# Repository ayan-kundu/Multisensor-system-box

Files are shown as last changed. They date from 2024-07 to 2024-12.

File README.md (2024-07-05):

# This is an Arduino IDE operational code 
## Hardware used: 
                  Arduino UNO with Adafruit SD card and RTC breakout module 
                  Sensors: 
                          Atlas CO2 industrial sesnor
                          RS 485 Soil probe sensor
                          RS 485 wall mountable Air sensor
                  Battery: 14.4V Li-ion rechargable battery 
## Running Software:
                  The software is customisable and optimised for the microcontroler and its computational capabilities alongside sesnor requirements for proper and robust communication 
                  In Code folder software sketch is included

### System in use: 
----It is a Prototype----
##### System Look
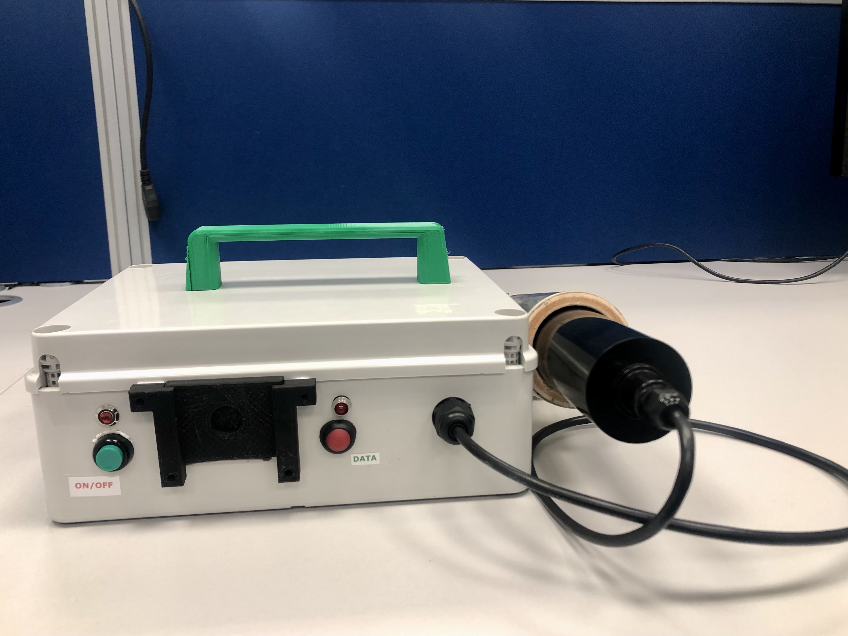
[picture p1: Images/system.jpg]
Multisesnor system box


##### In use On Desk
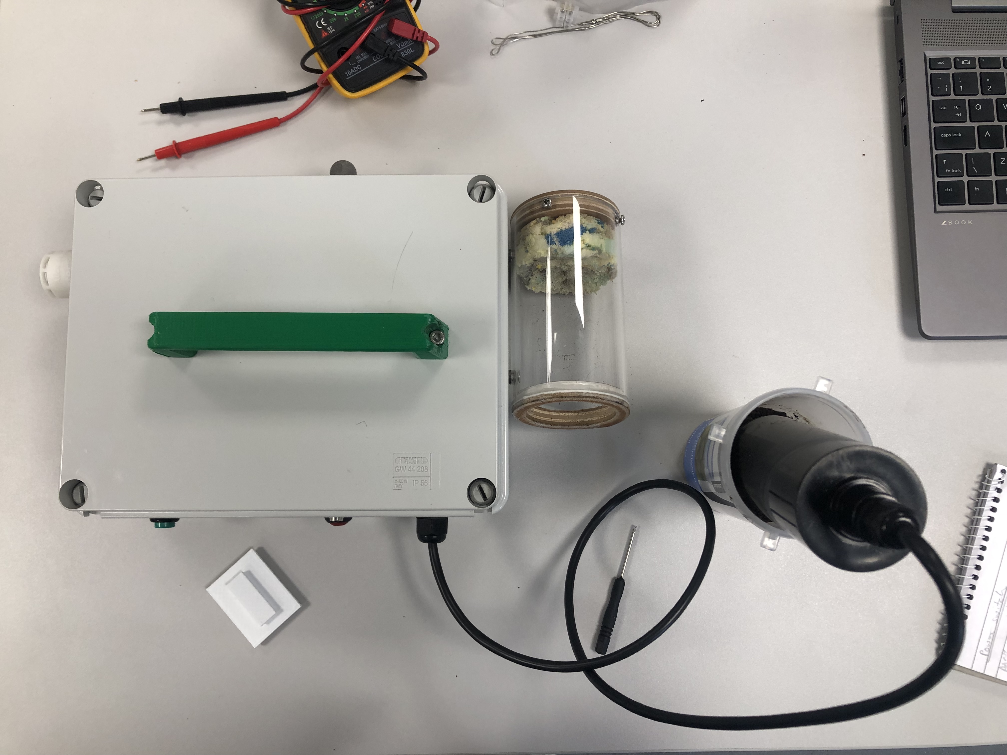
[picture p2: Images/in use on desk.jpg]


##### On Desk
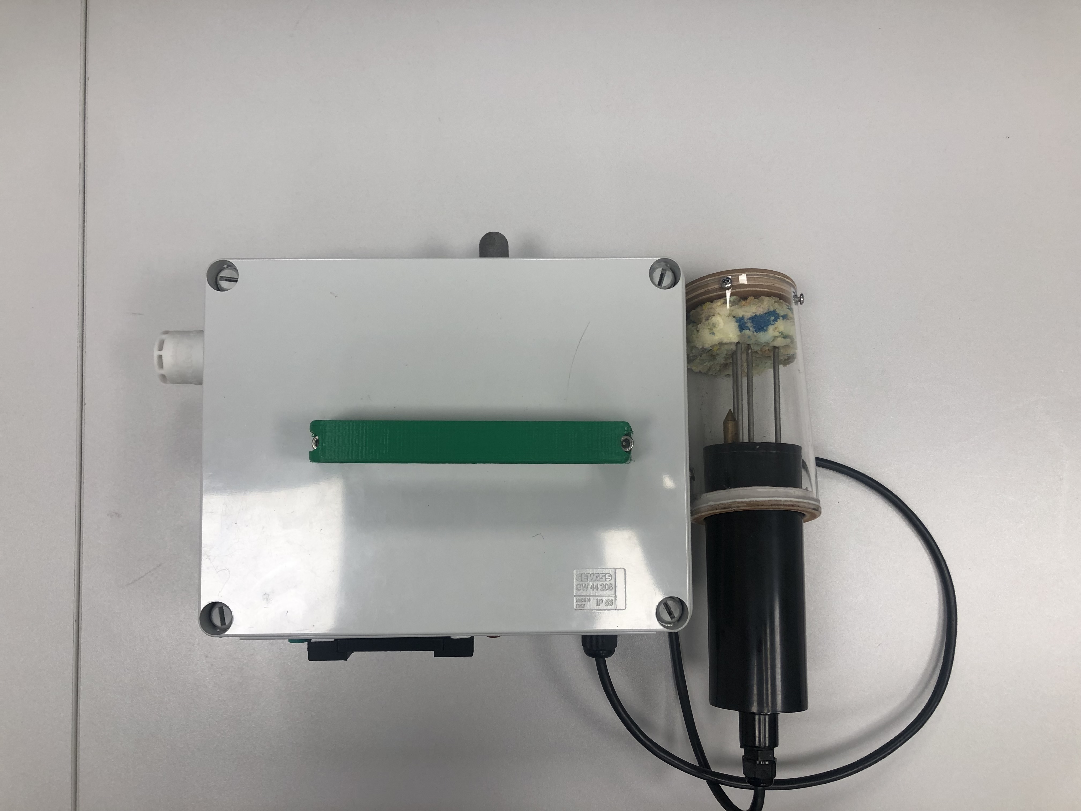
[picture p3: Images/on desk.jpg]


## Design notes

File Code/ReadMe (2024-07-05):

#Communication rrquirements for UNO
  Software serial alongside Altsoft Serial are used for communicating with RS485 and CO2 sensor respectedly
  CO2 sensor uses UART and AltsoftSerial is used for communication while Air and soil sensors use software serial for data interchange.
  Air and soil sensors use RS485 protocol and both of them are multidropped acrosse a Transiever names MAX485 which is connected to the arduino at one side whereas other side is attached to the sensor
  RX TX terminals 
#Optimisation was one of the most challenging part that came out as Arduino UNO has only 2K usable memories(Static and dynamic all together)
  Debugged version of the code is the latest and is more rubust to rough uses and stable reliable data encounter

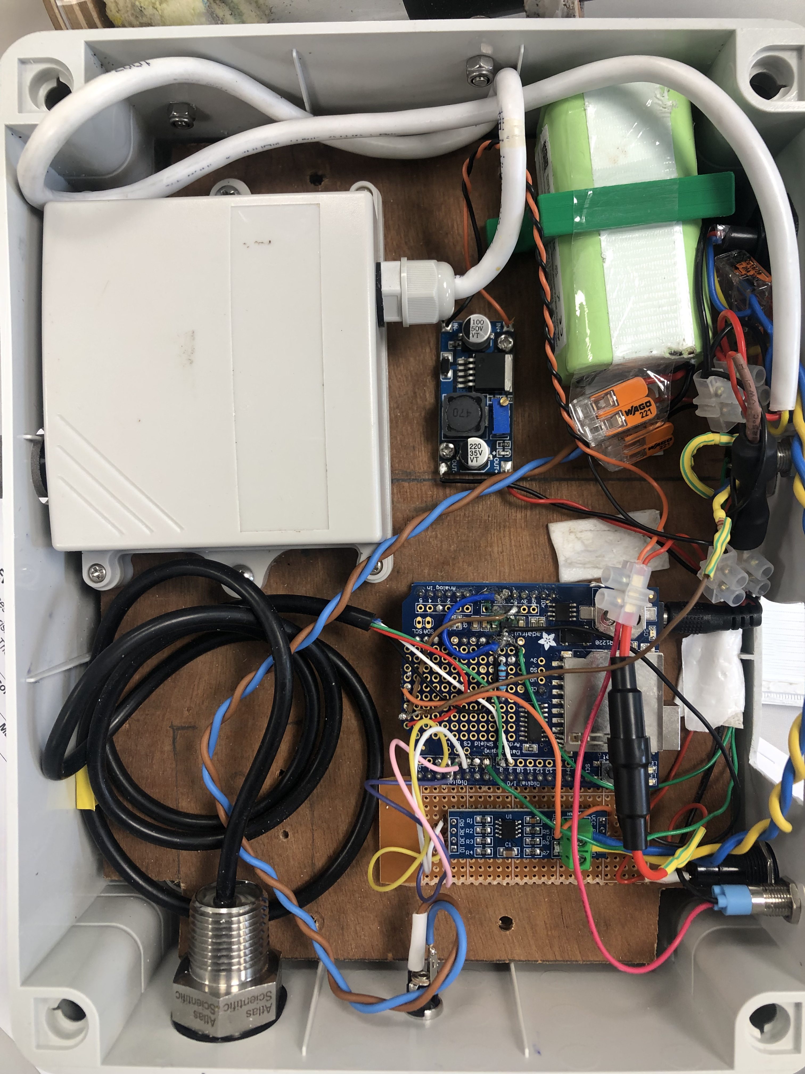
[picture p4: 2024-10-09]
Images/internal circuit.jpeg

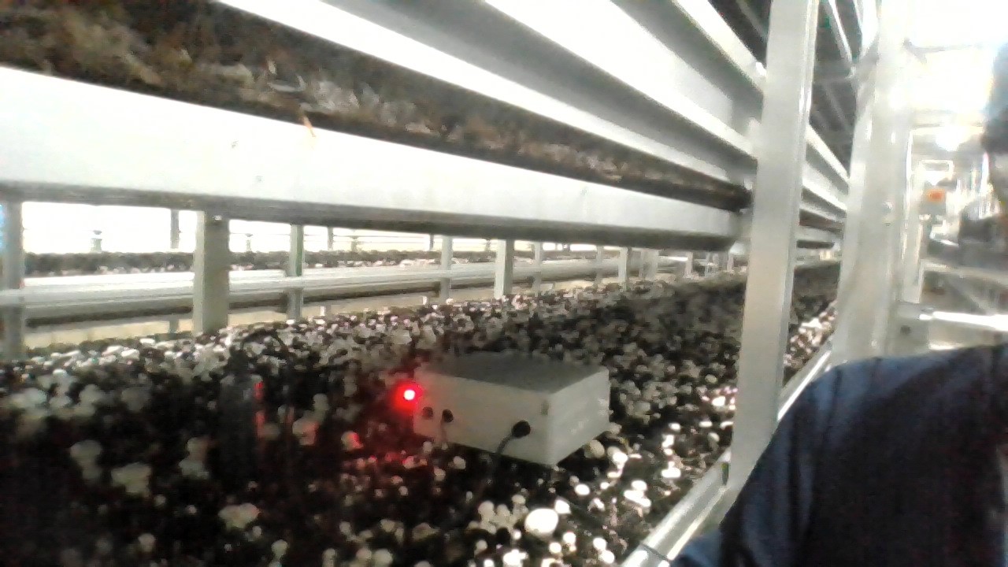
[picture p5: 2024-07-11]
Images/AtFarm/WIN_20240611_17_15_15_Pro.jpg

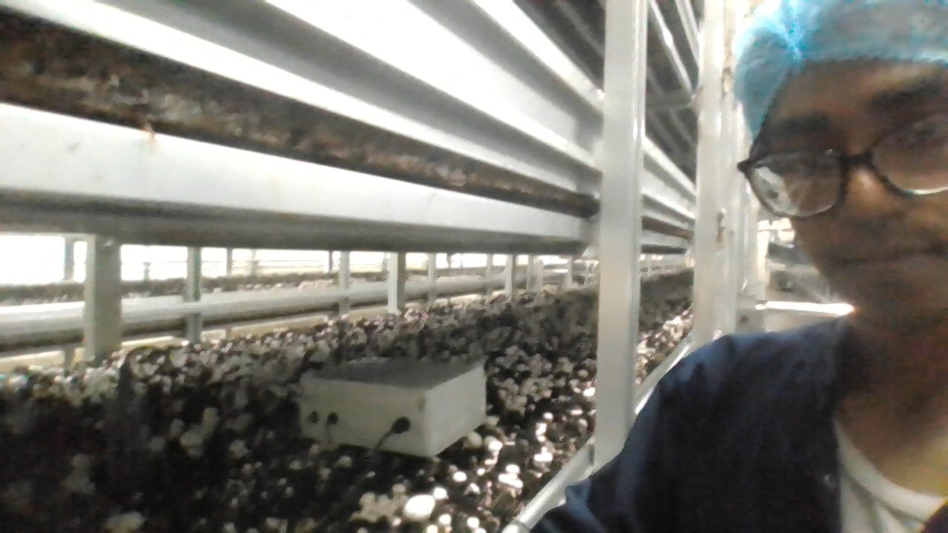
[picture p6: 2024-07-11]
Images/AtFarm/WIN_20240611_17_15_22_Pro.jpg

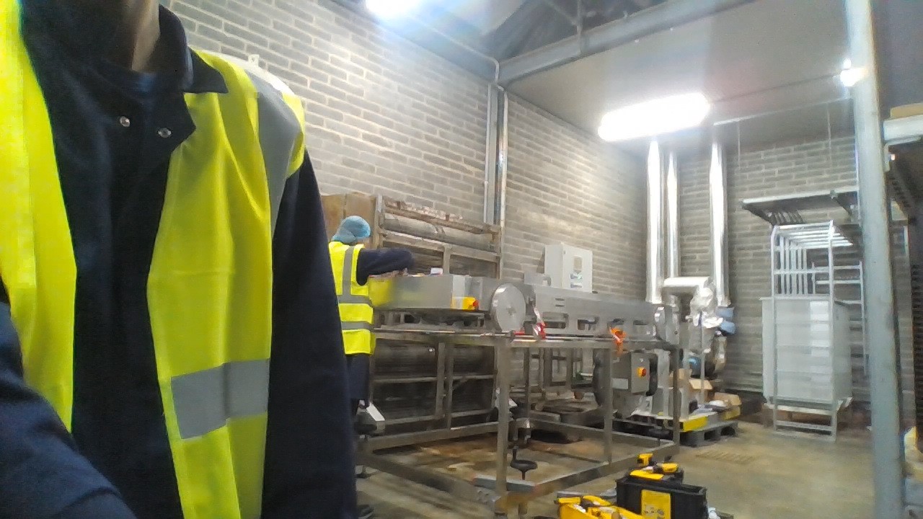
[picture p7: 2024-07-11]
Images/AtFarm/WIN_20240528_18_24_35_Pro.jpg

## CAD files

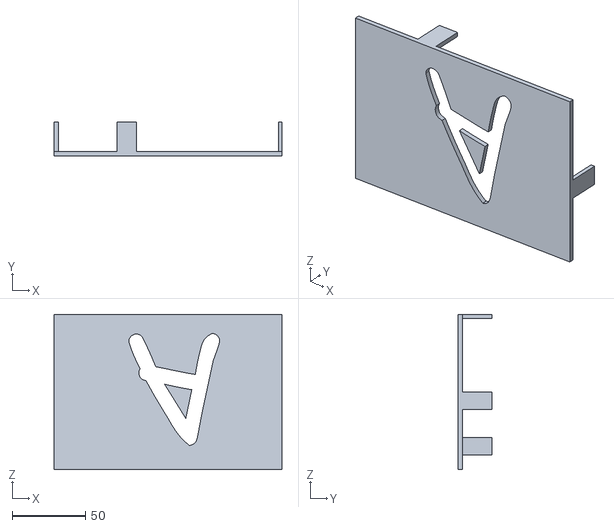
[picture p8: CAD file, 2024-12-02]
CAD/Sensor Board Lid v1.stl
155.7 x 23.0 x 105.8

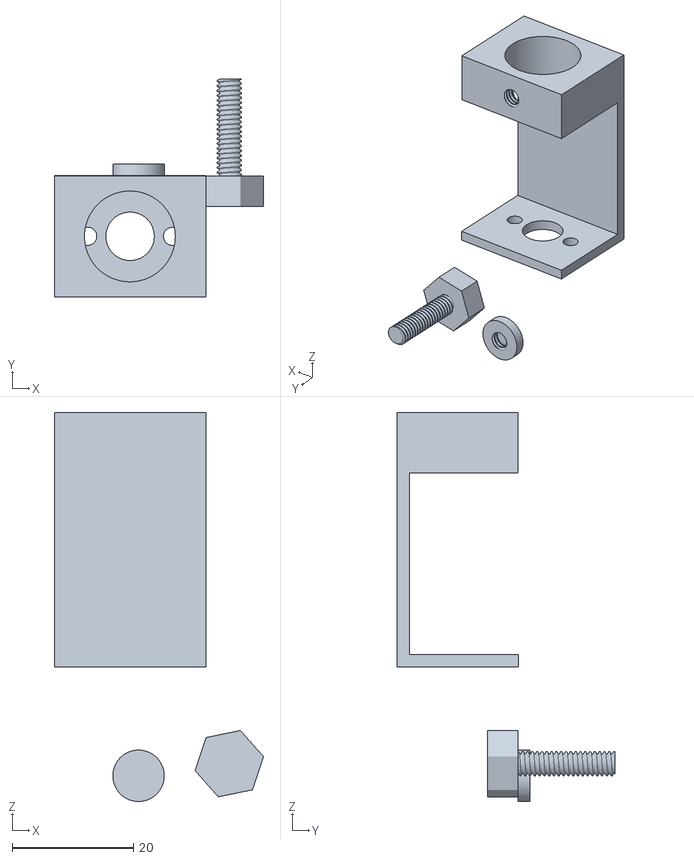
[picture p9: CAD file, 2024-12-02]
CAD/Gimbal Object hold Clip v1.stl
34.5 x 36.0 x 64.2

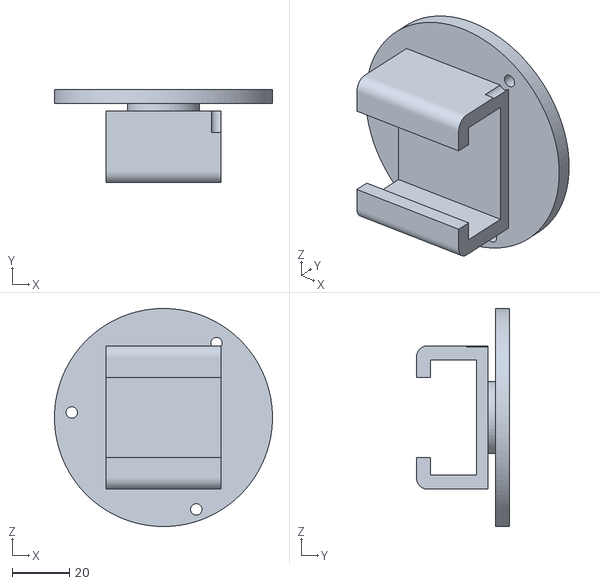
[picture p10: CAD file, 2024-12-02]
CAD/Al Extrusion clip v4.stl
76.0 x 32.5 x 76.0

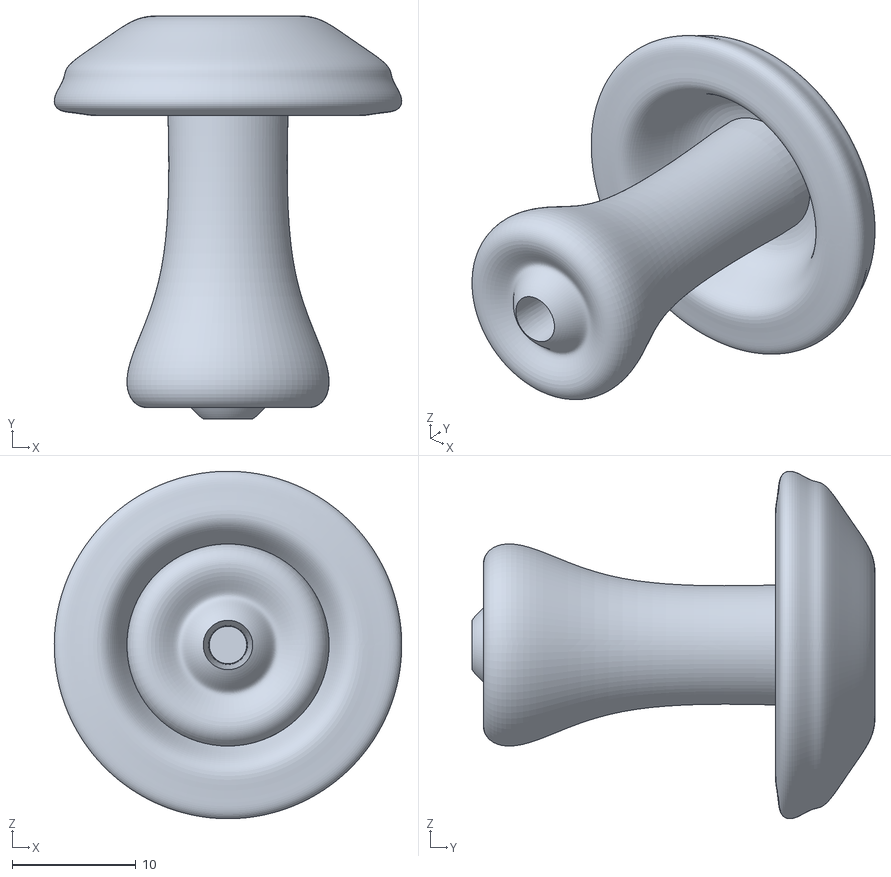
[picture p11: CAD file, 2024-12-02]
CAD/Mushroom v1.stl
28.1 x 32.6 x 28.1

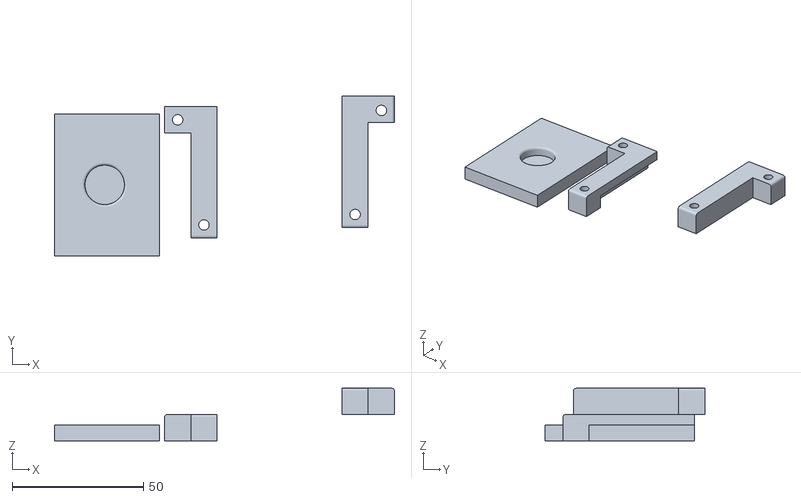
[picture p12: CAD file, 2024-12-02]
CAD/Slider Window Sensor box (v1~recovered).stl
129.4 x 60.7 x 20.0

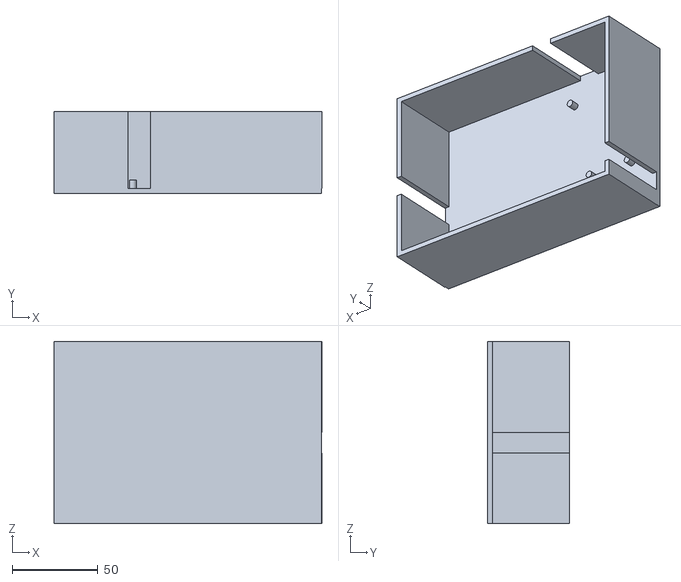
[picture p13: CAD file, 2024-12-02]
CAD/Sensor Board box v3.stl
156.0 x 48.0 x 106.0

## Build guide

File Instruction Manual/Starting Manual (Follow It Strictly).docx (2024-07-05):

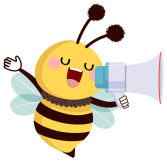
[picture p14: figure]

# Operating Manual (Follow It Strictly)

## Starting the box:

1. PUT SD card in
2. Press Green button (ON/OFF) to start and power the system
3. Allow 20 seconds to get it ready.
4. Start taking reading by pressing the red button.
5. Record reading from first bed and then move onto next bed and continue until you reach the last bed
6. Press Green button to turn OFF
7. Pull the SD card out
8. Copy data on cloud
9. Place SD card back

10.Done! Make sure power is OFF before leaving it

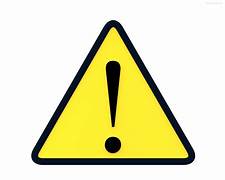
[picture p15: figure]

Please Handle with care, do not drop or place on an unstable surface

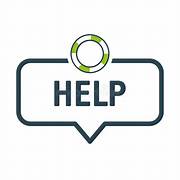
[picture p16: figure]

For battery charging, SD card and other detailed handling refer to Step-by-step guide manual.docx (https://universityoflincoln-my.sharepoint.com/:b:/g/personal/akundu_lincoln_ac_uk/EZc_OG_teqBHkJJpP_wEIkABpC4y5LWit84kSQEx2INEmg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)

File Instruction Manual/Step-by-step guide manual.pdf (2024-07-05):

## Step-by-Step Instructions for using the Multi-Sensor System Box at the Farm

This document describes how to use the portable sensor box used for taking environmental readings of a single growing shelf, using an ordered, step-by-step approach.
One set of sensor readings is required per growing bed, so 20 sets are required per shelf. One complete set of readings is taken whenever its red push-button is pressed.
Step 1:
Check the SD card whether it is inside the box where it is supposed to be. If the SD card is not inside place it before turning the system ON.
Power the device on by pushing the green ‘ON/OFF’ button once. (Pressing it again will turn it off). The red power LED illuminates when the system is ON. Wait at least 20 seconds to allow the system to warm up after power-on before taking a reading.
Step 2:
Find a suitable location near the middle of the bed to place the multi-pronged probe. Take the probe out of its holder and push it vertically into the compost until all its metal probes are completely buried.
Step 3:
Hold the sensor-box somewhere close to the middle of that bed, and as close to the top of the mushrooms as possible.
Step 4:
Push the red Data button, which is positioned on the side of the box. The red Data LED above will illuminate briefly to indicate that the button was pressed correctly, and a set of sensor readings have been taken. Try pushing the button again if the LED fails to light. Keep the probe and sensor box in place for about 5 seconds to ensure a good set of readings are taken.
Step 5:
Remove the probe from the bed and place it back into its holder on the side of the box.
Step 6:
Keeping the box powered on, move to the next bed and repeat steps 2...5 for all 20 beds.

Step 7:
Once the end of the shelf is reached and reading taken, please switch the unit off by pressing the green ON/OFF button once more. The red power LED will extinguish.
Step 9:
Please make sure power is OFF after use. Get back to a laptop where SD card can be plugged for reading.
Step 10:
SD Check – Once a whole set of data is taken, remove the SD card and copy the data on to the data sheet on cloud. Place the SD card back into the system box. Please do not go for reading collection without SD card to avoid missing data.
Battery Check- With low battery the power LED will illuminate dim; this means the system needs charging. If it needs charging, put it on charge for some time- around 20-30 minutes. DO NOT plug the Charger when system is ON. Put the Switch OFF and then place the charger in.

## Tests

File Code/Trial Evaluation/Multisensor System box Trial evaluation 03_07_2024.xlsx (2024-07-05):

Trial 1
1 | 12:12:45 | Co2:1784 CM:0.00 CT:22.60 AM:54.70 AT:22.30
2 | 12:12:48 | Co2:1775 CM:0.00 CT:22.60 AM:54.60 AT:22.20
3 | 12:12:51 | Co2:1773 CM:0.00 CT:22.60 AM:54.60 AT:22.30
4 | 12:12:53 | Co2:1773 CM:0.00 CT:22.90 AM:54.70 AT:22.40
5 | 12:12:56 | Co2:1775 CM:0.00 CT:22.70 AM:54.70 AT:22.30
6 | 12:12:59 | Co2:1775 CM:0.00 CT:22.70 AM:54.70 AT:22.30
7 | 12:13:01 | Co2:1776 CM:0.00 CT:22.50 AM:54.70 AT:22.30
8 | 12:13:04 | Co2:1777 CM:0.00 CT:22.60 AM:54.70 AT:22.30
9 | 12:13:06 | Co2:1778 CM:0.00 CT:22.60 AM:54.60 AT:22.30
10 | 12:13:09 | Co2:1779 CM:0.00 CT:22.60 AM:54.60 AT:22.30
11 | 12:13:12 | Co2:1780 CM:0.00 CT:22.50 AM:54.60 AT:22.30
12 | 12:13:14 | Co2:1779 CM:0.00 CT:22.50 AM:54.70 AT:22.40
13 | 12:13:17 | Co2:1777 CM:0.00 CT:22.50 AM:54.60 AT:22.30
14 | 12:13:19 | Co2:1772 CM:0.00 CT:22.50 AM:54.60 AT:22.40
15 | 12:13:22 | Co2:1771 CM:0.00 CT:22.60 AM:54.70 AT:22.30
16 | 12:13:24 | Co2:1771 CM:0.00 CT:22.60 AM:54.70 AT:22.40
17 | 12:13:27 | Co2:1769 CM:0.00 CT:22.50 AM:54.70 AT:22.40
18 | 12:13:29 | Co2:1766 CM:0.00 CT:22.40 AM:54.80 AT:22.40
19 | 12:13:32 | Co2:1764 CM:0.00 CT:22.60 AM:54.70 AT:22.30
20 | 12:13:34 | Co2:1766 CM:0.00 CT:22.40 AM:54.70 AT:22.40
Trial 2
1 | 12:17:10 | Co2:1840 CM:0.00 CT:22.70 AM:54.80 AT:22.30
2 | 12:17:12 | Co2:1840 CM:0.00 CT:22.60 AM:54.70 AT:22.40
3 | 12:17:14 | Co2:1838 CM:0.00 CT:22.50 AM:54.70 AT:22.40
4 | 12:17:16 | Co2:1837 CM:0.00 CT:22.50 AM:54.80 AT:22.40
5 | 12:17:18 | Co2:1836 CM:0.00 CT:22.70 AM:54.60 AT:22.40
6 | 12:17:20 | Co2:1835 CM:0.00 CT:22.90 AM:54.70 AT:22.40
7 | 12:17:22 | Co2:1833 CM:0.00 CT:22.70 AM:54.60 AT:22.40
8 | 12:17:24 | Co2:1832 CM:0.00 CT:22.50 AM:54.60 AT:22.40
9 | 12:17:26 | Co2:1830 CM:0.00 CT:22.60 AM:54.70 AT:22.30
10 | 12:17:28 | Co2:1828 CM:0.00 CT:22.70 AM:54.80 AT:22.40
11 | 12:17:30 | Co2:1827 CM:0.00 CT:22.60 AM:54.60 AT:22.30
12 | 12:17:32 | Co2:1826 CM:0.00 CT:22.60 AM:54.70 AT:22.40
13 | 12:17:34 | Co2:1824 CM:0.00 CT:22.40 AM:54.70 AT:22.40
14 | 12:17:36 | Co2:1824 CM:0.00 CT:22.40 AM:54.70 AT:22.40
15 | 12:17:38 | Co2:1821 CM:0.00 CT:22.50 AM:54.60 AT:22.40
16 | 12:17:40 | Co2:1821 CM:0.00 CT:22.60 AM:54.70 AT:22.40
17 | 12:17:41 | Co2:1821 CM:0.00 CT:22.70 AM:54.80 AT:22.40
18 | 12:17:43 | Co2:1813 CM:0.00 CT:22.70 AM:54.70 AT:22.30
19 | 12:17:45 | Co2:1813 CM:0.00 CT:22.60 AM:54.70 AT:22.40
20 | 12:17:47 | Co2:1811 CM:0.00 CT:22.80 AM:54.80 AT:22.30
Trial 3
1 | 12:19:26 | Co2:1840 CM:0.00 CT:22.40 AM:54.50 AT:22.30
2 | 12:19:28 | Co2:1840 CM:0.00 CT:22.60 AM:54.40 AT:22.40
3 | 12:19:30 | Co2:1839 CM:0.00 CT:22.40 AM:54.40 AT:22.30
4 | 12:19:32 | Co2:1841 CM:0.00 CT:22.50 AM:54.50 AT:22.40
5 | 12:19:34 | Co2:1842 CM:0.00 CT:22.70 AM:54.50 AT:22.50
6 | 12:19:36 | Co2:1842 CM:0.00 CT:22.90 AM:54.50 AT:22.40
7 | 12:19:38 | Co2:1840 CM:0.00 CT:22.60 AM:54.50 AT:22.30
8 | 12:19:40 | Co2:1836 CM:0.00 CT:22.40 AM:54.60 AT:22.40
9 | 12:19:42 | Co2:1836 CM:0.00 CT:22.40 AM:54.60 AT:22.40
10 | 12:19:44 | Co2:1833 CM:0.00 CT:22.60 AM:54.60 AT:22.50
11 | 12:19:46 | Co2:1831 CM:0.00 CT:22.70 AM:54.60 AT:22.30
12 | 12:19:48 | Co2:1831 CM:0.00 CT:22.80 AM:54.60 AT:22.40
13 | 12:19:50 | Co2:1828 CM:0.00 CT:22.70 AM:54.60 AT:22.50
14 | 12:19:52 | Co2:1826 CM:0.00 CT:22.50 AM:54.60 AT:22.30
15 | 12:19:54 | Co2:1824 CM:0.00 CT:22.60 AM:54.50 AT:22.40
16 | 12:19:55 | Co2:1823 CM:0.00 CT:22.70 AM:54.60 AT:22.40
17 | 12:19:57 | Co2:1821 CM:0.00 CT:22.70 AM:54.60 AT:22.40
18 | 12:19:59 | Co2:1821 CM:0.00 CT:22.50 AM:54.50 AT:22.40
19 | 12:20:01 | Co2:1820 CM:0.00 CT:22.60 AM:54.60 AT:22.40
20 | 12:20:03 | Co2:1817 CM:0.00 CT:22.70 AM:54.60 AT:22.50
Trial 4
1 | 12:26:06 | Co2:1832 CM:2.30 CT:22.30 AM:54.80 AT:22.40
2 | 12:26:08 | Co2:1834 CM:2.30 CT:22.20 AM:54.60 AT:22.50
3 | 12:26:10 | Co2:1834 CM:2.30 CT:22.30 AM:54.70 AT:22.50
4 | 12:26:12 | Co2:1835 CM:2.30 CT:22.20 AM:54.70 AT:22.50
5 | 12:26:14 | Co2:1835 CM:2.30 CT:22.00 AM:54.70 AT:22.50
6 | 12:26:16 | Co2:1835 CM:2.30 CT:22.10 AM:54.70 AT:22.50
7 | 12:26:17 | Co2:1835 CM:2.30 CT:22.20 AM:54.70 AT:22.40
8 | 12:26:19 | Co2:1835 CM:2.30 CT:22.50 AM:54.70 AT:22.40
9 | 12:26:21 | Co2:1835 CM:2.30 CT:22.30 AM:54.70 AT:22.60
10 | 12:26:23 | Co2:1835 CM:2.30 CT:22.10 AM:54.80 AT:22.50
11 | 12:26:25 | Co2:1835 CM:2.20 CT:22.30 AM:54.70 AT:22.50
12 | 12:26:26 | Co2:1835 CM:2.20 CT:22.20 AM:54.70 AT:22.50
13 | 12:26:28 | Co2:1835 CM:2.30 CT:22.20 AM:54.70 AT:22.50
14 | 12:26:30 | Co2:1835 CM:2.30 CT:22.30 AM:54.70 AT:22.50
15 | 12:26:32 | Co2:1835 CM:2.30 CT:22.30 AM:54.60 AT:22.50
16 | 12:26:34 | Co2:1836 CM:2.30 CT:21.90 AM:54.70 AT:22.50
17 | 12:26:36 | Co2:1837 CM:2.30 CT:22.20 AM:54.80 AT:22.50
18 | 12:26:38 | Co2:1840 CM:2.30 CT:22.00 AM:54.70 AT:22.50
19 | 12:26:40 | Co2:1840 CM:2.30 CT:22.40 AM:54.70 AT:22.40
20 | 12:26:42 | Co2:1845 CM:2.30 CT:22.50 AM:54.70 AT:22.50
Trial 4
1 | 12:29:42 | Co2:1943 CM:2.30 CT:22.20 AM:55.00 AT:22.40
2 | 12:29:43 | Co2:1943 CM:2.30 CT:22.10 AM:54.90 AT:22.50
3 | 12:29:45 | Co2:1943 CM:2.30 CT:22.20 AM:55.00 AT:22.60
4 | 12:29:46 | Co2:1943 CM:2.30 CT:22.10 AM:54.90 AT:22.50
5 | 12:29:48 | Co2:1943 CM:2.30 CT:22.00 AM:55.00 AT:22.40
6 | 12:29:50 | Co2:1941 CM:2.30 CT:22.20 AM:54.90 AT:22.50
7 | 12:29:51 | Co2:1941 CM:2.30 CT:22.20 AM:54.90 AT:22.50
8 | 12:29:53 | Co2:1940 CM:2.30 CT:22.20 AM:55.00 AT:22.60
9 | 12:29:55 | Co2:1940 CM:2.30 CT:22.20 AM:54.90 AT:22.50
10 | 12:29:56 | Co2:1940 CM:2.30 CT:22.20 AM:55.10 AT:22.50
11 | 12:29:58 | Co2:1938 CM:2.30 CT:22.20 AM:55.00 AT:22.60
12 | 12:30:00 | Co2:1938 CM:2.30 CT:22.00 AM:54.90 AT:22.50
13 | 12:30:01 | Co2:1938 CM:2.30 CT:22.20 AM:55.00 AT:22.50
14 | 12:30:03 | Co2:1938 CM:2.30 CT:22.10 AM:55.10 AT:22.60
15 | 12:30:04 | Co2:1938 CM:2.30 CT:22.30 AM:55.00 AT:22.60
16 | 12:30:06 | Co2:1935 CM:2.30 CT:22.50 AM:55.10 AT:22.60
17 | 12:30:08 | Co2:1935 CM:2.30 CT:22.30 AM:55.00 AT:22.50
18 | 12:30:09 | Co2:1935 CM:2.30 CT:22.10 AM:55.00 AT:22.50
19 | 12:30:11 | Co2:1935 CM:2.30 CT:22.10 AM:55.00 AT:22.50
20 | 12:30:12 | Co2:1935 CM:2.30 CT:22.00 AM:55.00 AT:22.50
Trial 5
1 | 13:56:11 | Co2:1636 CM:0.00 CT:22.80 AM:58.30 AT:21.30
2 | 13:56:13 | Co2:1636 CM:0.00 CT:22.70 AM:58.30 AT:21.30
3 | 13:56:14 | Co2:1632 CM:0.00 CT:22.90 AM:58.20 AT:21.30
4 | 13:56:16 | Co2:1628 CM:0.00 CT:23.10 AM:58.30 AT:21.30
5 | 13:56:18 | Co2:1622 CM:0.00 CT:22.70 AM:58.30 AT:21.30
6 | 13:56:20 | Co2:1622 CM:0.00 CT:22.80 AM:58.20 AT:21.30
7 | 13:56:22 | Co2:1615 CM:0.00 CT:22.90 AM:58.30 AT:21.30
8 | 13:56:24 | Co2:1609 CM:0.00 CT:22.70 AM:58.20 AT:21.30
9 | 13:56:26 | Co2:1603 CM:0.00 CT:22.80 AM:58.20 AT:21.30
10 | 13:56:28 | Co2:1603 CM:0.00 CT:23.00 AM:58.20 AT:21.30
11 | 13:56:29 | Co2:1598 CM:0.00 CT:22.60 AM:58.20 AT:21.30
12 | 13:56:31 | Co2:1595 CM:0.00 CT:22.70 AM:58.20 AT:21.40
13 | 13:56:33 | Co2:1595 CM:0.00 CT:22.70 AM:58.20 AT:21.40
14 | 13:56:35 | Co2:1591 CM:0.00 CT:22.90 AM:58.20 AT:21.30
15 | 13:56:37 | Co2:1588 CM:0.00 CT:22.80 AM:58.10 AT:21.30
16 | 13:56:39 | Co2:1585 CM:0.00 CT:22.70 AM:58.10 AT:21.30
17 | 13:56:41 | Co2:1581 CM:0.00 CT:22.70 AM:58.10 AT:21.30
18 | 13:56:43 | Co2:1578 CM:0.00 CT:22.80 AM:58.10 AT:21.30
19 | 13:56:45 | Co2:1578 CM:0.00 CT:22.70 AM:58.10 AT:21.40
20 | 13:56:46 | Co2:1572 CM:0.00 CT:22.80 AM:58.00 AT:21.30
Trial 6
1 | 14:12:57 | Co2:1269 CM:0.00 CT:23.10 AM:54.70 AT:22.00
2 | 14:13:09 | Co2:1240 CM:0.00 CT:23.20 AM:54.70 AT:22.10
3 | 14:13:15 | Co2:1231 CM:0.00 CT:22.70 AM:54.70 AT:22.10
4 | 14:13:22 | Co2:1218 CM:0.00 CT:22.70 AM:54.60 AT:22.00
5 | 14:13:30 | Co2:1217 CM:0.00 CT:22.90 AM:54.60 AT:22.10
6 | 14:13:35 | Co2:1221 CM:0.00 CT:22.80 AM:54.60 AT:22.00
7 | 14:13:42 | Co2:1217 CM:0.00 CT:22.80 AM:54.50 AT:22.10
8 | 14:13:50 | Co2:1200 CM:0.00 CT:22.90 AM:54.50 AT:22.10
9 | 14:13:59 | Co2:1206 CM:0.00 CT:22.80 AM:54.60 AT:22.10
10 | 14:14:08 | Co2:1237 CM:0.00 CT:22.90 AM:54.50 AT:22.20
11 | 14:14:19 | Co2:1269 CM:0.00 CT:22.80 AM:54.60 AT:22.10
12 | 14:14:25 | Co2:1287 CM:0.00 CT:22.90 AM:54.70 AT:22.10
13 | 14:14:35 | Co2:1311 CM:0.00 CT:22.80 AM:54.80 AT:22.10
14 | 14:14:44 | Co2:1305 CM:0.00 CT:22.70 AM:54.90 AT:22.10
15 | 14:14:51 | Co2:1275 CM:0.00 CT:22.80 AM:55.10 AT:22.00
16 | 14:14:57 | Co2:1257 CM:0.00 CT:22.70 AM:55.00 AT:22.20
17 | 14:15:07 | Co2:1268 CM:0.00 CT:22.70 AM:54.70 AT:22.10
18 | 14:15:13 | Co2:1275 CM:0.00 CT:22.80 AM:54.60 AT:22.10
19 | 14:15:20 | Co2:1303 CM:0.00 CT:22.70 AM:54.60 AT:22.10
20 | 14:15:26 | Co2:1337 CM:0.00 CT:23.10 AM:54.60 AT:22.20
Trial 7
1 | 14:25:33 | Co2:1532 CM:0.00 CT:22.80 AM:55.60 AT:22.40
2 | 14:25:36 | Co2:1563 CM:0.00 CT:22.90 AM:56.40 AT:22.40
3 | 14:25:39 | Co2:1597 CM:0.00 CT:22.70 AM:56.70 AT:22.30
4 | 14:25:44 | Co2:1709 CM:0.00 CT:22.80 AM:57.10 AT:22.40
5 | 14:25:46 | Co2:1765 CM:0.00 CT:22.80 AM:57.00 AT:22.40
6 | 14:25:50 | Co2:1907 CM:0.00 CT:23.10 AM:56.80 AT:22.30
7 | 14:25:55 | Co2:1957 CM:0.00 CT:22.70 AM:56.50 AT:22.40
8 | 14:25:58 | Co2:1950 CM:0.00 CT:23.00 AM:56.30 AT:22.50
9 | 14:26:02 | Co2:1910 CM:0.00 CT:23.00 AM:56.10 AT:22.40
10 | 14:26:07 | Co2:1844 CM:0.00 CT:23.00 AM:55.80 AT:22.40
11 | 14:26:10 | Co2:1772 CM:0.00 CT:22.70 AM:55.60 AT:22.40
12 | 14:26:14 | Co2:1703 CM:0.00 CT:22.90 AM:55.60 AT:22.40
13 | 14:26:19 | Co2:1627 CM:0.00 CT:22.90 AM:55.40 AT:22.50
14 | 14:26:22 | Co2:1580 CM:0.00 CT:23.00 AM:55.40 AT:22.40
15 | 14:26:26 | Co2:1559 CM:0.00 CT:22.80 AM:55.40 AT:22.50
16 | 14:26:30 | Co2:1548 CM:0.00 CT:22.90 AM:55.30 AT:22.40
17 | 14:26:34 | Co2:1525 CM:0.00 CT:22.90 AM:55.40 AT:22.30
18 | 14:26:38 | Co2:1509 CM:0.00 CT:22.50 AM:55.40 AT:22.40
19 | 14:26:42 | Co2:1497 CM:0.00 CT:22.80 AM:55.40 AT:22.40
20 | 14:26:46 | Co2:1509 CM:0.00 CT:22.90 AM:55.60 AT:22.40
21 | 14:26:50 | Co2:1540 CM:0.00 CT:22.80 AM:55.50 AT:22.30
22 | 14:26:55 | Co2:1578 CM:0.00 CT:22.80 AM:55.50 AT:22.40
23 | 14:26:59 | Co2:1619 CM:0.00 CT:22.70 AM:55.40 AT:22.40
24 | 14:27:02 | Co2:1630 CM:0.00 CT:23.10 AM:55.40 AT:22.30
25 | 14:27:07 | Co2:1634 CM:0.00 CT:22.70 AM:55.30 AT:22.30
26 | 14:27:09 | Co2:1633 CM:0.00 CT:22.50 AM:55.30 AT:22.40
27 | 14:27:12 | Co2:1617 CM:0.00 CT:22.80 AM:55.30 AT:22.40
28 | 14:27:16 | Co2:1595 CM:0.00 CT:22.60 AM:55.30 AT:22.40
29 | 14:27:20 | Co2:1573 CM:0.00 CT:22.90 AM:55.40 AT:22.30
Trial 8
1 | 14:31:15 | Co2:1383 CM:0.00 CT:23.00 AM:55.20 AT:22.40
2 | 14:31:21 | Co2:1388 CM:0.00 CT:22.70 AM:55.20 AT:22.40
3 | 14:31:27 | Co2:1408 CM:0.00 CT:22.90 AM:55.30 AT:22.30
4 | 14:31:31 | Co2:1411 CM:0.00 CT:22.90 AM:55.20 AT:22.30
5 | 14:31:35 | Co2:1419 CM:0.00 CT:22.90 AM:55.20 AT:22.30
6 | 14:31:40 | Co2:1425 CM:0.00 CT:22.80 AM:55.30 AT:22.40
7 | 14:31:43 | Co2:1427 CM:0.00 CT:22.80 AM:55.10 AT:22.40
8 | 14:31:47 | Co2:1427 CM:0.00 CT:22.80 AM:55.20 AT:22.40
9 | 14:31:51 | Co2:1418 CM:0.00 CT:22.90 AM:55.20 AT:22.30
10 | 14:31:56 | Co2:1411 CM:0.00 CT:22.80 AM:55.30 AT:22.40
11 | 14:32:00 | Co2:1402 CM:0.00 CT:22.90 AM:55.20 AT:22.40
12 | 14:32:04 | Co2:1396 CM:0.00 CT:22.80 AM:55.10 AT:22.30
13 | 14:32:07 | Co2:1391 CM:0.00 CT:22.80 AM:55.30 AT:22.40
14 | 14:32:11 | Co2:1381 CM:0.00 CT:23.00 AM:55.20 AT:22.40
15 | 14:32:16 | Co2:1361 CM:0.00 CT:23.00 AM:55.20 AT:22.30
16 | 14:32:20 | Co2:1346 CM:0.00 CT:22.60 AM:55.10 AT:22.40
17 | 14:32:24 | Co2:1333 CM:0.00 CT:22.70 AM:55.20 AT:22.40
18 | 14:32:29 | Co2:1326 CM:0.00 CT:22.90 AM:55.10 AT:22.30
19 | 14:32:33 | Co2:1326 CM:0.00 CT:22.70 AM:55.20 AT:22.40
20 | 14:32:37 | Co2:1326 CM:0.00 CT:22.90 AM:55.20 AT:22.30
21 | 14:32:40 | Co2:1325 CM:0.00 CT:22.80 AM:55.20 AT:22.30
22 | 14:32:44 | Co2:1326 CM:0.00 CT:22.80 AM:55.10 AT:22.30
Trial 9
1 | 14:36:03 | Co2:1424 CM:0.00 CT:22.70 AM:55.40 AT:22.40
2 | 14:36:07 | Co2:1419 CM:0.00 CT:22.80 AM:55.40 AT:22.40
3 | 14:36:11 | Co2:1419 CM:0.00 CT:22.60 AM:55.30 AT:22.30
4 | 14:36:15 | Co2:1426 CM:0.00 CT:22.80 AM:55.40 AT:22.40
5 | 14:36:19 | Co2:1426 CM:0.00 CT:22.90 AM:55.20 AT:22.50
6 | 14:36:24 | Co2:1429 CM:0.00 CT:22.90 AM:55.20 AT:22.40
7 | 14:36:28 | Co2:1422 CM:0.00 CT:22.80 AM:55.30 AT:22.40
8 | 14:36:32 | Co2:1408 CM:0.00 CT:22.80 AM:55.30 AT:22.40
9 | 14:36:37 | Co2:1389 CM:0.00 CT:22.90 AM:55.30 AT:22.40
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

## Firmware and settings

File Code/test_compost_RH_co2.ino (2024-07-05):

#include <SoftwareSerial.h>
#include <AltSoftSerial.h>

// Library for SD card
#include <SD.h>
#include <Wire.h>
#include "RTClib.h"
RTC_DS1307 rtc;

#define chipSelect 10  // for the data logging shield CS line
#define pushswitch 7   

/**** For RS sensor ****SoftwareSerial ****/

// Define the pins for RS485 communication
#define RX 5
#define TX 2
// enable pins
#define RE 4
#define DE 3

// Request frame for the soil sensor
SoftwareSerial modbus(RX, TX);  // Software serial for RS485 communication
/**** For CO2 sensor **** AltSoftwareSerial ****/

//define how the soft serial port is going to work
AltSoftSerial myserial;  // Arduino pin 9 :: Tx; pin 8 :: Rx

String sensorstring = "";                
String outputstring = "";

boolean sensor_string_complete = false;  
int Co2_value;



void setup() {
  /*For soil sensor*/
  Serial.flush();
  Serial.begin(9600);  
  modbus.begin(9600);  

  pinMode(RE, OUTPUT);  
  pinMode(DE, OUTPUT);  

  /*For CO2 sensor*/
  myserial.begin(9600);
  sensorstring.reserve(20);  
  outputstring.reserve(60);
  Wire.begin();
  rtc.begin();

  // Initialise SD card
  pinMode(10, OUTPUT);
  if (!SD.begin(10)) {
    //Serial.println("Card failed");
  }

  rtc.begin();
  if (!rtc.begin()) {
    //Serial.println("Couldn't find RTC");
    Serial.flush();
    while (1) delay(10);
  }
  if (!rtc.isrunning()) {
    //rtc.adjust(DateTime(F(__DATE__), F(__TIME__)));//CR1220 Battery
  }
  DateTime now = rtc.now();
  File myFile;
  myFile = SD.open("DT.txt", O_CREAT | O_APPEND | O_WRITE);
  delay(50);
  myFile.println();
  myFile.println(String("\t\t\t\t--- Data logging --- ") + now.timestamp(DateTime::TIMESTAMP_DATE));  // This line takes 50 bytes
  //myFile.println();
  myFile.close();
  /**** Set up Push Switch ****/
  pinMode(pushswitch, INPUT_PULLUP);  // switch bridged to GND
}




void loop() {
  Serial.flush();
  DateTime noww = rtc.now(); /*** Try avoid print statement ***/

  // Call functions/sensors
  Co2_value = CO2();

  /**** Push switch operation ****/
  int pushSwitchState = digitalRead(pushswitch);  // pin 7
  File myFile;
  if (pushSwitchState == LOW) {
    delay(50);  // switch debouncing
    float temperature_Celsius;
    float Moisture_Percent = soilSensor(&temperature_Celsius);
    delay(200);
    float air_temperature_Celsius;
    float air_Moisture_Percent = RHSensor(&air_temperature_Celsius);
    //Open file
    myFile = SD.open("DT.txt", O_CREAT | O_APPEND | O_WRITE);
    //myFile.print(noww.timestamp(DateTime::TIMESTAMP_TIME));  // adding this interupts serial time display
    outputstring=String("\tCo2:") + Co2_value + String(" CM:") + Moisture_Percent + String(" CT:") + temperature_Celsius + String(" AM:") + air_Moisture_Percent + String(" AT:") + air_temperature_Celsius;
    myFile.println(noww.timestamp(DateTime::TIMESTAMP_TIME)+outputstring);
    // Try avoid unnecessary variables and lines
    myFile.close();
    myFile.flush();
    //Serial.println("->");
    //Serial.println(String("\tCo2:") + Co2_value + String("ppm | Moisture: ") + Moisture_Percent + String("% | Temp: ") + temperature_Celsius+String("°C | RH: ")+air_Moisture_Percent+String("% | Air Temp: ")+air_temperature_Celsius+String("°C"));
  }


  /*******************************************/
  delay(250);  
}

float soilSensor(float *temp) {
  float Temperature_Celsius;
  float Moisture_Percent;
  const byte soilSensorRequest[] = { 0x01, 0x03, 0x00, 0x00, 0x00, 0x02, 0xC4, 0x0B };
  byte soilSensorResponse[9];
  /*Start the transmission mode for RS485 */
  digitalWrite(DE, HIGH);
  digitalWrite(RE, HIGH);
  delay(10);

  // Send the request frame to the soil sensor
  modbus.write(soilSensorRequest, sizeof(soilSensorRequest));

  /*End the transmission mode and set to receive mode for RS485*/
  digitalWrite(DE, LOW);
  digitalWrite(RE, LOW);
  delay(10);

  // Wait for the response from the sensor or timeout after 1 second
  unsigned long startTime = millis();
  while (modbus.available() < 9 && millis() - startTime < 1000) {
    delay(1);  // help continue the loop
  }
  if (modbus.available() >= 9)  // If valid response received
  {
    // Read the response from the sensor
    byte index = 0;
    while (modbus.available() && index < 9) {
      soilSensorResponse[index] = modbus.read();
      //Serial.print(soilSensorResponse[index], HEX); // Print the received byte in HEX format
      //Serial.print(" ");
      index++;
    }
    //Serial.println("Compost sensor Response Read");
    /* Parse and calculate the Moisture value */

    int Moisture_Int = int(soilSensorResponse[5] << 8 | soilSensorResponse[6]);
    Moisture_Percent = Moisture_Int / 10.0;

    //Serial.println(String("->Moisture content: ")+Moisture_Percent+ String(" %"));
    /* Parse and calculate the Temperature value */

    int Temperature_Int = int(soilSensorResponse[3] << 8 | soilSensorResponse[4]);
    Temperature_Celsius = Temperature_Int / 10.0;
    *temp = Temperature_Celsius;

  }
  return Moisture_Percent;
}


int CO2() {

  int Co2;
  if (myserial.available() > 0) {  
    char inchar = (char)myserial.read();  
    if (inchar != '\r') {                 
      sensorstring += inchar;             
      if (isdigit(sensorstring[0])) {
        Co2 = sensorstring.toInt();
      }
    }

    else {
      sensorstring = "";  // decouple readings per
      sensor_string_complete = true;
    }
    if (sensor_string_complete == true) {  
      Co2_value = Co2;

    }
    sensor_string_complete = false;  
  }
  //modbus.listen();
  return Co2_value;
}


float RHSensor(float *air_temp) {  //float *air_temp
  float air_Temperature_Celsius;
  float air_Moisture_Percent;
  const byte RHSensorRequest[] = { 0x02, 0x03, 0x00, 0x00, 0x00, 0x02, 0xC4, 0x38 };
  byte RHSensorResponse[9];
  /*Start the transmission mode for RS485 */
  digitalWrite(DE, HIGH);
  digitalWrite(RE, HIGH);
  delay(10);

  // Send the request frame to the soil sensor
  modbus.write(RHSensorRequest, sizeof(RHSensorRequest));

  /*End the transmission mode and set to receive mode for RS485*/
  digitalWrite(DE, LOW);
  digitalWrite(RE, LOW);
  delay(10);

  // Wait for the response from the sensor or timeout after 1 second
  unsigned long startTime = millis();
  while (modbus.available() < 9 && millis() - startTime < 1000) {
    delay(1);  
    /**** Reading response frame and store it ****/
    if (modbus.available() >= 9){
      byte index = 0;
      while (modbus.available() && index < 9) {
        RHSensorResponse[index] = modbus.read();
        //Serial.print(soilSensorResponse[index], HEX); // Print the received byte in HEX format
        //Serial.print(" ");
        index++;
      }
      /* Parse and calculate the Moisture value */

      int Moisture_Int = int(RHSensorResponse[5] << 8 | RHSensorResponse[6]);
      air_Moisture_Percent = Moisture_Int / 10.0;

      //Serial.println(String("->Moisture content: ")+Moisture_Percent+ String(" %"));
      /* Parse and calculate the Temperature value */

      int Temperature_Int = int(RHSensorResponse[3] << 8 | RHSensorResponse[4]);
      air_Temperature_Celsius = Temperature_Int / 10.0;
      *air_temp = air_Temperature_Celsius;
    }

  } 
  return air_Moisture_Percent;
}
